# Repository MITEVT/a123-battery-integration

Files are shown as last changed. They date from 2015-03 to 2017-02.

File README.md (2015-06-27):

# a123-battery-integration
Battery Management System for A123 Battery-Brusa Charger combination.
## Target
NXP LPC11Cxx series ARM Cortex-M0
## Description
Interfaces between A123 Module CAN Bus and Brusa CAN Bus and sets appropriate voltage and current profiles. Essentially a battery control module.
### Referenced Library Files
* [EVT's LPC11xx Library](https://github.com/MITEVT/lpc11cx4-library)
* [Unity](https://github.com/ThrowTheSwitch/Unity)

### Requirements
```
gcc-arm-none-eabi
doxygen
oclint
```

### Looking for Examples?
* [EVT's LPC11xx Library](https://github.com/MITEVT/lpc11cx4-library)

### Trying to configure sysinit.c?
Use CMSIS Configuration Wizard v0.0.6
* http://helmpcb.com/software/cmsis-configuration-wizard
* https://sourceforge.net/projects/cmsisconfig/

## More info about our team
http://web.mit.edu/evt/

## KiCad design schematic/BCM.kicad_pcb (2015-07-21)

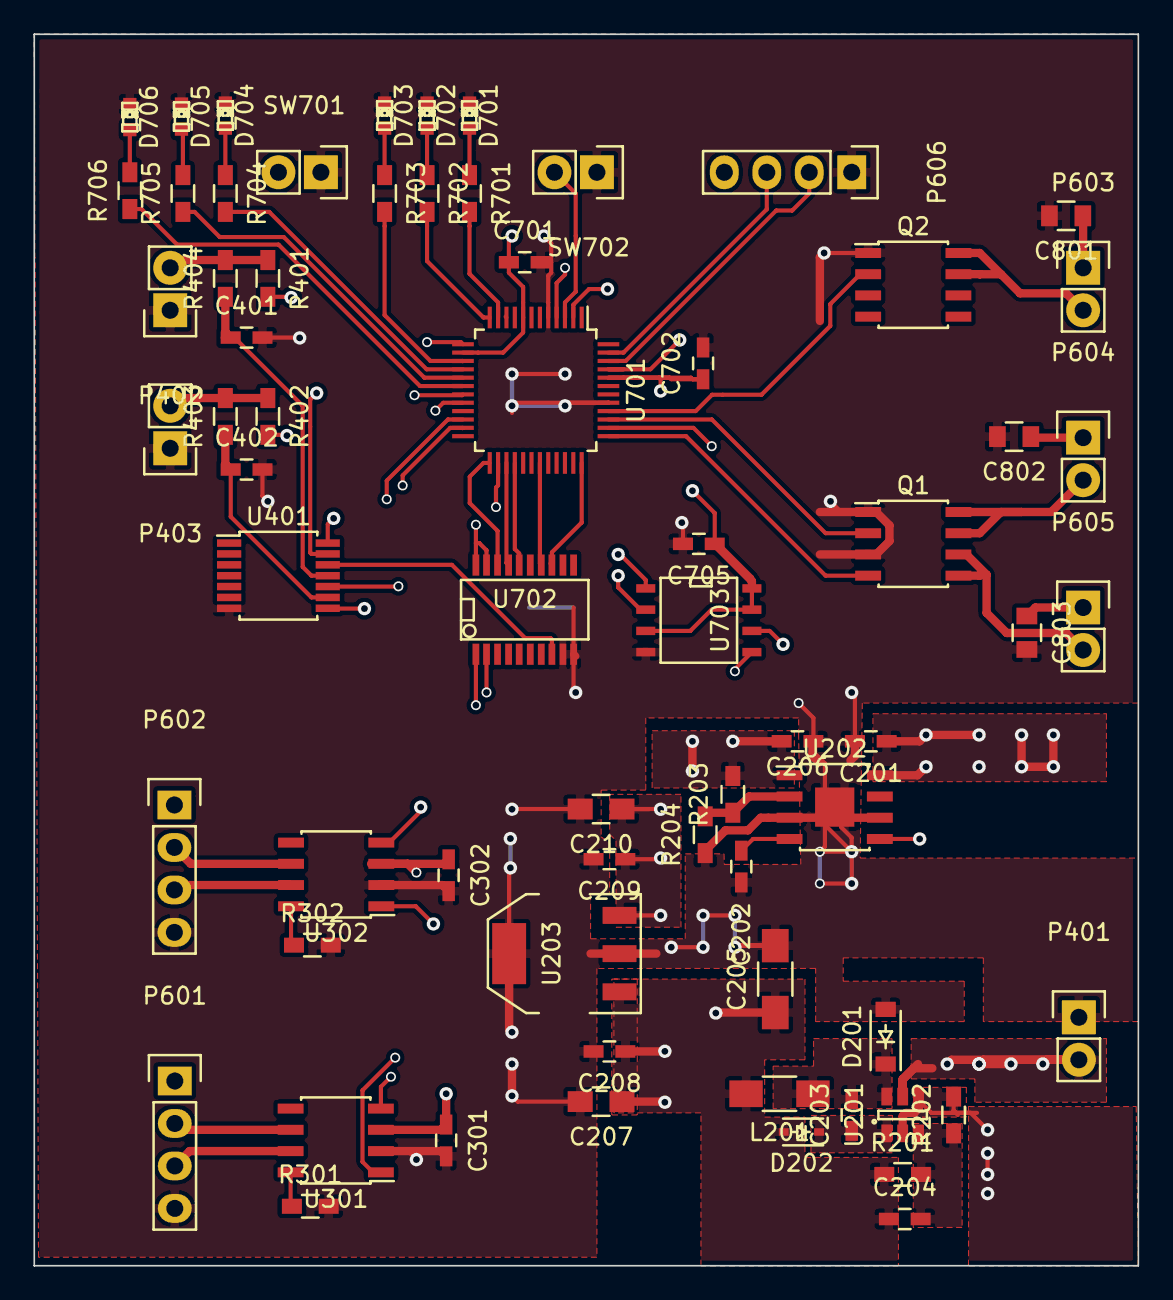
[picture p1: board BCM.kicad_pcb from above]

Board: 4 copper layers, 66.0 x 73.7 mm, 67 parts (0 on the bottom side), 59 nets.

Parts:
C201, C206, C401, C402: 1uF; C_0603_HandSoldering
C202: 10nF; C_0603_HandSoldering
C203: 0.22pF; C_0603_HandSoldering
C204: 10pF; C_0603_HandSoldering
C205: 100uF; C_1206_HandSoldering
C207, C210: 10u; C_0805_HandSoldering
C208, C209, C701, C702: 100n; C_0603_HandSoldering
C301, C302, C705: 0.1uF; C_0603_HandSoldering
C801, C802, C803: 10uF; C_0805
D201: MBR0540; SOD-123
D202: CMDSH-3; SOD-323
D701, D702, D703, D704, D705, D706: RED; LED-0603
L201: 47uH; C_1206_HandSoldering
P401: POWERCON; Pin_Header_Straight_1x02
P402: KEYSWITCH; Pin_Header_Straight_1x02
P403: CHARGESW; Pin_Header_Straight_1x02
P601: BRUSA_CANCON; Pin_Header_Straight_1x04
P602: A123_CANCON; Pin_Header_Straight_1x04
P603: CON+; Pin_Header_Straight_1x02
P604: CON-; Pin_Header_Straight_1x02
P605: CONPRE; Pin_Header_Straight_1x02
P606: UART; Pin_Header_Straight_1x04
Q1, Q2: IRF7101PbF; SOIC-8_3.9x4.9mm_Pitch1.27mm
R201: 1M; R_0603_HandSoldering
R202: 604K; R_0603_HandSoldering
R203: 88.7k; R_0603_HandSoldering
R204: 10k; R_0603_HandSoldering
R301, R302: 33k; R_0603_HandSoldering
R401, R402, R403, R404: 20k; R_0603_HandSoldering
R701, R702, R703, R704, R705, R706: 1k; R_0603_HandSoldering
SW701: ISP; Pin_Header_Straight_1x02
SW702: RESET; Pin_Header_Straight_1x02
U201: LT1934; SOT-23-6
U202: ADP7105; SOIC-8-1EP_3.9x4.9mm_Pitch1.27mm
U203: SPX2920M3-3.3; SOT-223
U301, U302: MCP2551-I/SN; SOIC-8_3.9x4.9mm_Pitch1.27mm
U401: 74LS14; TSSOP-14_4.4x5mm_Pitch0.65mm
U701: LPC11C14; LQFP-48_7x7mm_Pitch0.5mm
U702: MCP2515_TSSOP; SSOP-20
U703: AT25XX; SOIC-8-N

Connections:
+3V3: C209.1, C210.1, C701.1, C702.1, C705.1, R401.2, R402.2, U203.3, U401.14, U701.8, U701.14, U701.44, U702.19, U702.20, U703.3, U703.7, U703.8
+5V: C204.1, C205.1, C207.1, C208.1, C301.1, C302.1, D202.2, L201.2, P606.4, R201.1, U203.1, U301.3, U302.3
+12V: C206.1, P602.1, R203.1, U202.1
+15V: C201.1, C801.1, C802.1, C803.1, P401.2, P603.1, P604.1, P605.1, U201.5, U202.8
/Can transceiver/CAN1_H_I: P601.2, U301.6
/Can transceiver/CAN1_L_I: P601.3, U301.7
/Can transceiver/CAN1_RS: R301.1, U301.8
/Can transceiver/CAN1_RX: U301.4, U702.2
/Can transceiver/CAN1_TX: U301.1, U702.1
/Can transceiver/CAN2_H_I: P602.2, U302.6
/Can transceiver/CAN2_L_I: P602.3, U302.7
/Can transceiver/CAN2_RS: R302.1, U302.8
/Can transceiver/CAN2_RX: U302.4, U701.19
/Can transceiver/CAN2_TX: U302.1, U701.20
/Contactor Driver/CON+: Q2.2, U701.40
/Contactor Driver/CON+_LOW: P603.2, Q2.7, Q2.8
/Contactor Driver/CON-: Q1.2, U701.39
/Contactor Driver/CON-_LOW: P604.2, Q1.7, Q1.8
/Contactor Driver/CONPRE: Q1.4, U701.37
/Contactor Driver/CONPRE_LOW: P605.2, Q1.5, Q1.6
/Input Connectors/CHARGESWITCH_R: P403.2, R402.1, R403.2
/Input Connectors/CHARGESWITCH_RC: C402.1, R403.1, U401.9
/Input Connectors/KEYSKWITCH_RC: C401.1, R404.1, U401.11
/Input Connectors/KEYSWITCH_R: P402.2, R401.1, R404.2
/Power/5V0_BOOST: C203.1, D202.1, U201.1
/Power/5V0_FB: C204.2, R201.2, R202.1, U201.3
/Power/5V0_L: C203.2, D201.1, L201.1, U201.6
/Power/12V0_FB: R203.2, R204.1, U202.2
/Power/12V0_SS: C202.1, U202.4
/Power/EN12V0: U202.5, U701.45
/microController/CAN1_INT: U701.36, U702.13
/microController/CAN1_MISO: U701.27, U702.17
/microController/CAN1_MOSI: U701.28, U702.16
/microController/CAN1_SCK: U701.31, U702.14
/microController/CAN1_SSEL: U701.25, U702.18
/microController/CAN_OSC2: U401.12, U702.8
/microController/CHARGESWITCH_IN: U401.8, U701.22
/microController/CLKOUT: SW701.2, U401.13, U701.4
/microController/IO_LED0: R701.2, U701.11
/microController/IO_LED1: R702.2, U701.12
/microController/IO_LED2: R703.2, U701.15
/microController/IO_LED3: R704.2, U701.16
/microController/IO_LED4: R705.1, U701.17
/microController/IO_LED5: R706.1, U701.18
/microController/KEYSWITCH_IN: U401.10, U701.23
/microController/MCU_RESET: SW702.2, U701.3
/microController/MCU_RXD: P606.2, U701.46
/microController/MCU_TXD: P606.3, U701.47
/microController/PROM_MISO: U701.26, U703.2
/microController/PROM_MOSI: U701.38, U703.5
/microController/PROM_SCK: U701.13, U703.6
/microController/PROM_SSEL: U701.2, U703.1
GND: C201.2, C202.2, C205.2, C206.2, C207.2, C208.2, C209.2, C210.2, C301.2, C302.2, C401.2, C402.2, C701.2, C702.2, C705.2, C801.2, C802.2, C803.2, D201.2, D701.1, D702.1, D703.1, D704.1, D705.1, D706.1, P401.1, P402.1, P403.1, P601.4, P602.4, P606.1, Q1.1, Q1.3, Q2.1, R202.2, R204.2, R301.2, R302.2, SW701.1, SW702.1, U201.2, U201.4, U202.3, U202.6, U202.9, U203.2, U203.4, U301.2, U302.2, U401.7, U701.5, U701.41, U702.9, U702.10, U703.4
unnamed: D701.2, R701.1
unnamed: D702.2, R702.1
unnamed: D703.2, R703.1
unnamed: D704.2, R704.1
unnamed: D705.2, R705.2
unnamed: D706.2, R706.2

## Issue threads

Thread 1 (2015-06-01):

What do you think of this use of GOTO?

ericponce, 2015-06-01:
I used GOTOs to prevent a lag in the updating of output state variables in the charge state machine. I think using this one goto isn't too bad, but let me know what you think

ericponce, 2015-06-01:
Look at charge.c for the referenced code. (Or git diff the last commit)

Closed 2015-11-02.

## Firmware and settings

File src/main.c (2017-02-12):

/**
 * @file main.c
 * @author Eric Ponce
 * @date 23 June 2015
 * @brief Main Program File
 */

#include "board.h"
#include "config.h"
#include <string.h>
#include <stdlib.h>

#define UART_BAUD 57600
#define SPI_BAUD  500000
#define CCAN_BAUD 500000

#define UART_RX_BUF_SIZE 0x8
#define CCAN_BUF_SIZE 0x10

#define MCP_BAUD_KHZ  500
#define MCP_INP_CLK_MHZ 11
#define MCP_SJW 1
#define MCP_CS_GPIO 2
#define MCP_CS_PIN 2
#define MCP_INT_GPIO 0
#define MCP_INT_PIN 2

#define MBB_STD_MSG_OBJ 1
#define MBB_EXT_1_MSG_OBJ 2
#define MBB_EXT_2_MSG_OBJ 3
#define MBB_EXT_3_MSG_OBJ 4
#define MBB_EXT_4_MSG_OBJ 5
#define BCM_STD_MSG_OBJ 6
#define BCM_EXT_MSG_OBJ 7

#define BCM_POLL_IDLE_FREQ 1
#define BCM_POLL_CHARGING_FREQ 40
#define BCM_POLL_DRAINING_FREQ 40
#define BCM_POLL_BALANCING_FREQ 40

#define TIMED_MESSAGE_DELAY 1000

#define BRUSA_MAX_MAINS_CAMPS 1500

#define Hertz2Ticks(freq) SystemCoreClock / freq

#define UpdateBCMTimerFreq(freq) (Chip_TIMER_SetMatch(LPC_TIMER32_1, 0, Hertz2Ticks(freq)))

// ------------------------------------------------
// Global Static Variables

static volatile uint64_t msTicks; // Milliseconds 

// Uart
uint8_t Rx_Buf[UART_RX_BUF_SIZE];
static char str[100]; // For use with printing
// static char int_str[100]; // For use with printing in interrupts

// Off-Chip CAN
static CCAN_MSG_OBJ_T mcp_msg_obj;
static NLG5_CTL_T brusa_control;
static NLG5_STATUS_T brusa_status;
static NLG5_ACT_I_T brusa_actual_1;
static NLG5_ACT_II_T brusa_actual_2;
static NLG5_TEMP_T brusa_temp;
static NLG5_ERR_T brusa_error;
static NLG5_MESSAGES_T brusa_messages;
static volatile bool brusa_message_send = false;

// On-Chip CCAN
static CCAN_MSG_OBJ_T can_msg_obj;
static RINGBUFF_T rx_buffer;
static CCAN_MSG_OBJ_T _rx_buffer[CCAN_BUF_SIZE];
static uint8_t std_msg_send_count;

// A123 CAN Message Structures
static MBB_CMD_T mbb_cmd;

// State staging variables
static volatile bool new_std_msg_sent = true;

// State Variables
static MODE_T mode = IDLE;
static PACK_STATE_T pack_state;
static OUTPUT_STATE_T out_state;

// Timed Print
static uint64_t last_debug_message = 0;
static uint32_t message_count = 0;

// ------------------------------------------------
// Helper functions that don't belong in util because systick, printing, etc

/**
 * @details Relies on SysTick and therefore will not function with interrupts 
 * disabled or in a higher priority interrupt
 * 
 * @param ms number of milliseconds to delay
 */
void _delay_ms(uint32_t ms) {
	uint32_t currTicks = msTicks;
	while(msTicks - currTicks < ms) {

	}
}

/**
 * @details Throws error through multiple means: print, flash, and/or hang
 * 
 * @param errorNo The error number
 * @param flashLED set to true to have processor flash the main LED
 * @param hang set to true to hang the processor
 */
void _error(ERROR_T errorNo, bool flashLED, bool hang) {
	DEBUG_Print("Error(");
	itoa(errorNo, str, 10);
	DEBUG_Print(str);
	DEBUG_Print(")\r\n");

	do { // Hang forevers
		if (flashLED) {
			uint8_t i;
			for (i = 0; i < errorNo; i++) {
				Board_LED_Off();
				_delay_ms(500);
				Board_LED_On();
				_delay_ms(500);
			}
		}
		_delay_ms(1500);
		Board_LED_Off();
	} while(hang);

	Board_LED_On();
}

// ------------------------------------------------
// IRQs

/**
 * @details Increments millisecond counter
 */
void SysTick_Handler(void) {
	msTicks++;
}

/**
 * @details Timer interrupt to maintain Brusa communication timing
 */
void TIMER32_0_IRQHandler(void) {
	if (Chip_TIMER_MatchPending(LPC_TIMER32_0, 0)) {
		Chip_TIMER_ClearMatch(LPC_TIMER32_0, 0);

		brusa_message_send = true;
	}
}

/**
 * @details Timer interrupt to request A123 MBB information
 */
void TIMER32_1_IRQHandler(void) {
	Chip_TIMER_ClearMatch(LPC_TIMER32_1, 0);
	// Update Battery Status
	if (RingBuffer_IsEmpty(&rx_buffer)) {
		// Send BCM_CMD
		mbb_cmd.request_type = BCM_REQUEST_TYPE_STD;
		mbb_cmd.request_id = 5;
		mbb_cmd.balance = out_state.balance;
		mbb_cmd.balance_target_mVolts = out_state.balance_mVolts;

		can_msg_obj.msgobj = BCM_STD_MSG_OBJ;
		MBB_MakeCMD(&mbb_cmd, &can_msg_obj);
		LPC_CCAN_API->can_transmit(&can_msg_obj);	

		new_std_msg_sent = true;
		if (std_msg_send_count++ == 4) {
			std_msg_send_count = 0;

			mbb_cmd.request_type = BCM_REQUEST_TYPE_EXT;
			can_msg_obj.msgobj = BCM_EXT_MSG_OBJ;
			mbb_cmd.request_id = 6;
			MBB_MakeCMD(&mbb_cmd, &can_msg_obj);
			LPC_CCAN_API->can_transmit(&can_msg_obj);

		}
	}
}

// ------------------------------------------------
// CAN Callbacks

/**
 * @details Moves received on-chip CAN messages into ring buffer
 * 
 * @param msg_obj_num CAN message object that received message
 */
void CAN_rx(uint8_t msg_obj_num) {
	/* Determine which CAN message has been received */
	can_msg_obj.msgobj = msg_obj_num;
	/* Now load up the msg_obj structure with the CAN message */
	LPC_CCAN_API->can_receive(&can_msg_obj);
	RingBuffer_Insert(&rx_buffer, &can_msg_obj);
}


/**
 * @details On-chip CAN transmit callback. Currently does nothing
 * 
 * @param msg_obj_num CAN message object that sent message
 */
void CAN_tx(uint8_t msg_obj_num) {
	msg_obj_num++;
}

/**
 * @details On-chip CAN error callback. Currently does nothing
 * 
 * @param error_info error info
 */
void CAN_error(uint32_t error_info) {
	error_info++;
	DEBUG_Print("On-chip CAN Error\n\r");
	// _error(error_info, true, false);
}

// ------------------------------------------------
// Init Functions

/**
 * @details Initializes SysTick Peripheral
 */
void Init_Core(void) {
	SystemCoreClockUpdate();

	msTicks = 0; 

	// ------------------------------------------------
	// Systick Config
	if (SysTick_Config (SystemCoreClock / 1000)) {
		//Error
		while(1);
	}
}

/**
 * @details Initializes state machines and sets configuration data
 */
void Init_SM(void) {

	CHARGING_CONFIG_T charge_config;
	charge_config.pack_s = CELL_SERIES;
	charge_config.pack_p = CELL_PARALLEL;
	charge_config.max_cell_mVolts = 3600;
	charge_config.cc_cell_mVolts = 3700;
	charge_config.cell_capacity_cAmpHours = 2000; 	// 20 Ahr
	charge_config.cell_mC_rating = 133; 			// .133 C

	DRAINING_CONFIG_T drain_config;
	drain_config.min_cell_mVolts = 2500; //Specs say 2000mV but lets play it safe for now

	Charge_Config(&charge_config);
	Drain_Config(&drain_config);
	SSM_Init();
	PackManager_Init();

}

/**
 * @details Initializes board peripherals
 */
void Init_Board(void) {
	// ------------------------------------------------
	// Board Periph Init
	Board_LED_Init();
	Board_LED_On();
	Board_Switch_Init(SWITCH1);
	Board_Switch_Init(SWITCH2);
	Board_Contactors_Init();

	// ------------------------------------------------
	// Communication Init

	Board_UART_Init(UART_BAUD);
	Board_SPI_Init(SPI_BAUD);
	Board_CCAN_Init(CCAN_BAUD, CAN_rx, CAN_tx, CAN_error);
}

/**
 * @details Initializes statically allocated global variables
 */
void Init_Globals(void) {
	brusa_control.enable = 1;
	brusa_control.clear_error = 0;
	brusa_control.ventilation_request = 1;
	brusa_control.max_mains_cAmps = BRUSA_MAX_MAINS_CAMPS;
	brusa_control.output_mV = 0;
	brusa_control.output_cA = 0;

	pack_state.pack_min_mVolts = 0xFFFFFFFF;
	pack_state.pack_max_mVolts = 0;
	pack_state.pack_cAmps_in = 0;

	out_state.balance_mVolts = BCM_BALANCE_OFF;
	out_state.balance = false;
	out_state.brusa_mVolts = 0;
	out_state.brusa_cAmps = 0;
	out_state.close_contactors = false;
	out_state.brusa_output = false;
	out_state.brusa_clear_latch = false;

	mode = IDLE;

	std_msg_send_count = 0;

	brusa_messages.stat = &brusa_status;
	brusa_messages.act_i = &brusa_actual_1;
	brusa_messages.act_ii = &brusa_actual_2;
	brusa_messages.temp = &brusa_temp;
	brusa_messages.err = &brusa_error;
}

/**
 * @details Initializes both on-chip and off-chip CAN and sets up filters and masks.
 */
void Init_CAN(void) {
	// ------------------------------------------------
	// MCP2515 Init
	MCP2515_Init(MCP_CS_GPIO, MCP_CS_PIN, MCP_INT_GPIO, MCP_INT_PIN);
	uint8_t i = MCP2515_SetBitRate(MCP_BAUD_KHZ, MCP_INP_CLK_MHZ, MCP_SJW);
	itoa(i, str, 10);
	if (i) {
		DEBUG_Print("Baud Error: ");
		DEBUG_Print(str);
		DEBUG_Print("\r\n");
		_error(ERROR_CAN_BUS, true, true);
	}

	Brusa_MakeCTL(&brusa_control, &mcp_msg_obj);
	MCP2515_LoadBuffer(0, &mcp_msg_obj);

	MCP2515_BitModify(RXB0CTRL, RXM_MASK, RXM_STD); //Turn RXB0 Mask
	MCP2515_BitModify(RXB1CTRL, RXM_MASK, RXM_STD);
	MCP2515_BitModify(RXF0SIDH, 0xFF, 0xC2);
	MCP2515_BitModify(RXF0SIDL, 0xE0, 0x00); // Message 610
	MCP2515_BitModify(RXF1SIDH, 0xFF, 0xC2);
	MCP2515_BitModify(RXF1SIDL, 0xE0, 0x80); // Message 614
	MCP2515_BitModify(RXM0SIDH, 0xFF, 0xFF);
	MCP2515_BitModify(RXM0SIDL, 0xE0, 0xE0); // Buffer 0 gets odd
	MCP2515_BitModify(RXF2SIDH, 0xFF, 0xC2);
	MCP2515_BitModify(RXF2SIDL, 0xE0, 0x20); // Message 611
	MCP2515_BitModify(RXF3SIDH, 0xFF, 0xC2);
	MCP2515_BitModify(RXF3SIDL, 0xE0, 0x60); // Message 613
	MCP2515_BitModify(RXF4SIDH, 0xFF, 0xC2);
	MCP2515_BitModify(RXF4SIDL, 0xE0, 0x20); // Message 611
	MCP2515_BitModify(RXF5SIDH, 0xFF, 0xC2);
	MCP2515_BitModify(RXF5SIDL, 0xE0, 0x20); // Message 611
	MCP2515_BitModify(RXM1SIDH, 0xFF, 0xFF);
	MCP2515_BitModify(RXM1SIDL, 0xE0, 0xE0); // Buffer 1 gets even

	MCP2515_Mode(MODE_NORMAL);

	// ------------------------------------------------
	// On-Chip CCAN Init
	RingBuffer_Init(&rx_buffer, _rx_buffer, sizeof(CCAN_MSG_OBJ_T), 8);
	RingBuffer_Flush(&rx_buffer);

	// MBB_STD
	can_msg_obj.msgobj = MBB_STD_MSG_OBJ;
	can_msg_obj.mode_id = 0x200;
	can_msg_obj.mask = 0xF00;
	LPC_CCAN_API->config_rxmsgobj(&can_msg_obj);

	// MBB_EXT_1
	can_msg_obj.msgobj = MBB_EXT_1_MSG_OBJ;
	can_msg_obj.mode_id = 0x300;
	can_msg_obj.mask = 0xF00;
	LPC_CCAN_API->config_rxmsgobj(&can_msg_obj);

	// MBB_EXT_2
	can_msg_obj.msgobj = MBB_EXT_2_MSG_OBJ;
	can_msg_obj.mode_id = 0x400;
	can_msg_obj.mask = 0xF00;
	LPC_CCAN_API->config_rxmsgobj(&can_msg_obj);

	// MBB_EXT_3
	can_msg_obj.msgobj = MBB_EXT_3_MSG_OBJ;
	can_msg_obj.mode_id = 0x500;
	can_msg_obj.mask = 0xF00;
	LPC_CCAN_API->config_rxmsgobj(&can_msg_obj);

	// MBB_EXT_4
	can_msg_obj.msgobj = MBB_EXT_4_MSG_OBJ;
	can_msg_obj.mode_id = 0x600;
	can_msg_obj.mask = 0xF00;
	LPC_CCAN_API->config_rxmsgobj(&can_msg_obj);
}

/**
 * @details Initiizes timers for timer based interrupts
 */
void Init_Timers(void) {
	// ------------------------------------------------
	// Timer 32_0 Init
	Chip_TIMER_Init(LPC_TIMER32_0);
	Chip_TIMER_Reset(LPC_TIMER32_0);
	Chip_TIMER_MatchEnableInt(LPC_TIMER32_0, 0);
	Chip_TIMER_SetMatch(LPC_TIMER32_0, 0, Hertz2Ticks(10));
	Chip_TIMER_ResetOnMatchEnable(LPC_TIMER32_0, 0);

    // Chip_TIMER_Enable(LPC_TIMER32_0);

	/* Enable timer interrupt */
	NVIC_ClearPendingIRQ(TIMER_32_0_IRQn);
	NVIC_EnableIRQ(TIMER_32_0_IRQn);

	// ------------------------------------------------
	// Timer 32_0 Init
	Chip_TIMER_Init(LPC_TIMER32_1);
	Chip_TIMER_Reset(LPC_TIMER32_1);
	Chip_TIMER_MatchEnableInt(LPC_TIMER32_1, 0);
	Chip_TIMER_SetMatch(LPC_TIMER32_1, 0, Hertz2Ticks(BCM_POLL_IDLE_FREQ));
	Chip_TIMER_ResetOnMatchEnable(LPC_TIMER32_1, 0);

	/* Enable timer_32_1 interrupt */
	NVIC_ClearPendingIRQ(TIMER_32_1_IRQn);
	NVIC_EnableIRQ(TIMER_32_1_IRQn);

	Chip_TIMER_Enable(LPC_TIMER32_1);
}


// ------------------------------------------------
// Main Program

/**
 * @details Where all the magic happens
 * @return Shouldn't return
 */
int main(void) {

	Init_Core();
	Init_SM();
	Init_Board();
	Init_Globals();
	Init_CAN();
	Init_Timers();

	// ------------------------------------------------
	// Begin

	DEBUG_Print("Started Up\r\n");

	while(1) {

		uint8_t count;
		if ((count = Chip_UART_Read(LPC_USART, Rx_Buf, UART_RX_BUF_SIZE)) != 0) {
			switch (Rx_Buf[0]) {
				case 'a': // Print out Brusa Mains Info
					DEBUG_Print("Actual Mains Voltage: ");
					itoa(brusa_actual_1.mains_mVolts, str, 10);
					DEBUG_Print(str);
					DEBUG_Print("\r\n");

					DEBUG_Print("Mains type: ");
					itoa(brusa_actual_1.mains_cAmps, str, 10);
					DEBUG_Print(str);
					DEBUG_Print("\r\n");

					DEBUG_Print("Temp: ");
					itoa((brusa_temp.power_temp / 10) - 40 , str, 10);
					DEBUG_Print(str);
					DEBUG_Print("\r\n");

					DEBUG_Print("Temp: 0x");
					itoa(brusa_temp.power_temp , str, 16);
					DEBUG_Print(str);
					DEBUG_Print("\r\n");
					break;
				case 'b': // Print out Actual Brusa Output
					DEBUG_Print("Actual Out Voltage: ");
					itoa(brusa_actual_1.output_mVolts, str, 10);
					DEBUG_Println(str);

					DEBUG_Print("Actual Out Current: ");
					itoa(brusa_actual_1.output_cAmps, str, 10);
					DEBUG_Println(str);
					break;
				case 'f': // Print out Pack State
					itoa(pack_state.pack_min_mVolts, str, 10);
					DEBUG_Print("Pack Min Voltage: ");
					DEBUG_Print(str);
					DEBUG_Print("\r\n");
					itoa(pack_state.pack_max_mVolts, str, 10);
					DEBUG_Print("Pack Max Voltage: ");
					DEBUG_Print(str);
					DEBUG_Print("\r\n");

					break;
				case 'y': // Print out Module Balance State
					itoa(PackManager_GetExtModId(0), str, 16);
					DEBUG_Print("Mod 0x");
					DEBUG_Print(str);
					itoa(PackManager_GetExtBal(0), str, 2);
					DEBUG_Print(": 0b");
					DEBUG_Println(str);
					itoa(PackManager_GetExtModId(1), str, 16);
					DEBUG_Print("Mod 0x");
					DEBUG_Print(str);
					itoa(PackManager_GetExtBal(1), str, 2);
					DEBUG_Print(": 0b");
					DEBUG_Println(str);
					break;
				case 'e': 
					itoa(brusa_error,str, 2);
					DEBUG_Println(str);
					break;
				case 'm': // Print out charge mode and brusa error
					DEBUG_Print("Charge Mode: ");
					itoa(Charge_GetMode(), str, 10);
					DEBUG_Println(str);
					DEBUG_Print("Error Messages: ");
					itoa((uint64_t)brusa_error, str, 2);
					DEBUG_Println(str);
					break;
				default:
					DEBUG_Print("Unknown Command\r\n");
			}
		}

		//-----------------------------
		// Detect Input Changes (Default to IDLE)

		MODE_INPUT_T inp = INP_IDLE;
		if (!Board_Switch_Read(SWITCH1)) {
			inp = INP_CHRG;
		} else {
			inp = INP_IDLE;
		}

		if (!Board_Switch_Read(SWITCH2)) {
			inp = INP_BALANCE;
		}

		//-----------------------------
		// Update pack_state
		pack_state.contactors_closed = Board_Contactors_Closed();
		pack_state.msTicks = msTicks;
		pack_state.brusa_error = brusa_error;
		pack_state.pack_cAmps_in = brusa_actual_1.output_cAmps;

		//-----------------------------
		// SSM Step
		ERROR_T result = SSM_Step(&pack_state, inp, &out_state);
		if (result != ERROR_NONE) {
			_error(result, true, false);
		}

		//-----------------------------
		// Check if SSM has Changed State
		// Currently only changes Poll Frequency
		// [TODO] Set a status LED!!
		if (SSM_GetMode() != mode) {
			mode = SSM_GetMode();
			switch (SSM_GetMode()) {
				case IDLE:
					Chip_TIMER_SetMatch(LPC_TIMER32_1, 0, Hertz2Ticks(BCM_POLL_IDLE_FREQ));
					Chip_TIMER_Reset(LPC_TIMER32_1); // Otherwise shit gets FUCKED
					break;
				case CHARGING:
					Chip_TIMER_SetMatch(LPC_TIMER32_1, 0, Hertz2Ticks(BCM_POLL_CHARGING_FREQ));
					Chip_TIMER_Reset(LPC_TIMER32_1);
					break;
				case DRAINING:
					Chip_TIMER_SetMatch(LPC_TIMER32_1, 0, Hertz2Ticks(BCM_POLL_DRAINING_FREQ));
					Chip_TIMER_Reset(LPC_TIMER32_1);
					break;
				case BALANCING:
					Chip_TIMER_SetMatch(LPC_TIMER32_1, 0, Hertz2Ticks(BCM_POLL_BALANCING_FREQ));
					Chip_TIMER_Reset(LPC_TIMER32_1);
					break;
			}
		}

		//-----------------------------
		// Carry out out_state
		if (out_state.close_contactors && !Board_Contactors_Closed()) {
			Board_Close_Contactors(true);
		} else if (!out_state.close_contactors && Board_Contactors_Closed()) {
			Board_Close_Contactors(false);
		}

		if (out_state.brusa_output) {
			brusa_control.clear_error = out_state.brusa_clear_latch;
			brusa_control.output_mV = out_state.brusa_mVolts;
			brusa_control.output_cA = out_state.brusa_cAmps;
			Chip_TIMER_Enable(LPC_TIMER32_0);
		} else {
			brusa_control.output_mV = 0;
			brusa_control.output_cA = 0;
			Chip_TIMER_Disable(LPC_TIMER32_0);
		}

		//-----------------------------
		// Retrieve available brusa messages
		int8_t tmp = MCP2515_GetFullReceiveBuffer();
		int8_t res = 0;
		if (tmp == 2) {
			MCP2515_ReadBuffer(&mcp_msg_obj, 0);
			res = Brusa_Decode(&brusa_messages, &mcp_msg_obj);
			if (res == -1) {
				DEBUG_Println("Brusa Decode Error");
				res = 0;
			}
			MCP2515_ReadBuffer(&mcp_msg_obj, 1);
			res = Brusa_Decode(&brusa_messages, &mcp_msg_obj);
		} else if (tmp == 0) { // Receive Buffer 0 Full
			MCP2515_ReadBuffer(&mcp_msg_obj, tmp);
			res = Brusa_Decode(&brusa_messages, &mcp_msg_obj);
		} else if (tmp == 1) { //Receive buffer 1 full
			MCP2515_ReadBuffer(&mcp_msg_obj, tmp);
			res = Brusa_Decode(&brusa_messages, &mcp_msg_obj);
		} 

		if (res == -1) {
			DEBUG_Println("Brusa Decode Error");
			res = 0;
		}

		//-----------------------------
		// Send brusa message if its time
		if (brusa_message_send) {
			brusa_message_send = false;
			Brusa_MakeCTL(&brusa_control, &mcp_msg_obj);
			MCP2515_LoadBuffer(0, &mcp_msg_obj);
			MCP2515_SendBuffer(0);
		}
		
		//-----------------------------
		// Check for and decode A123 Messages
		if (!RingBuffer_IsEmpty(&rx_buffer)) {

			CCAN_MSG_OBJ_T temp_msg;
			RingBuffer_Pop(&rx_buffer, &temp_msg);
			res = PackManager_Update(&temp_msg);

			if (new_std_msg_sent) {
				PackManager_Commit(&pack_state);
				new_std_msg_sent = false;
			}
			
		}

		if (res == -1) {
			DEBUG_Println("A123 Decode Error");
		}

		//-----------------------------
		// Timed output
		if (msTicks - last_debug_message > TIMED_MESSAGE_DELAY) {
			message_count++;
			last_debug_message = msTicks;
			switch (message_count % 7) {
				case 0:
					if (out_state.balance) {
						itoa(mbb_cmd.balance_target_mVolts, str, 10);
						DEBUG_Print("Balancing to: ");
						DEBUG_Println(str);
					} else {
						DEBUG_Println("Not balancing");
					}
					
					break;
				case 1:
					itoa(brusa_control.output_mV, str, 10);
					DEBUG_Print("Brusa out V: ");
					DEBUG_Println(str);
					break;
				case 2:
					itoa(brusa_control.output_cA, str, 10);
					DEBUG_Print("Brusa out C: ");
					DEBUG_Println(str);
					break;
				case 3:
					DEBUG_Print("Actual Out Voltage: ");
					itoa(brusa_actual_1.output_mVolts, str, 10);
					DEBUG_Println(str);
					break;
				case 4:
					DEBUG_Print("Actual Out Current: ");
					itoa(brusa_actual_1.output_cAmps, str, 10);
					DEBUG_Println(str);
					break;
				case 5:
					DEBUG_Print("Mode: ");
					if (SSM_GetMode() == CHARGING) {
						DEBUG_Println("Chrg");
					} else if (SSM_GetMode() == DRAINING) {
						DEBUG_Println("Drain");
					} else if (SSM_GetMode() == BALANCING) {
						DEBUG_Println("Bal");
					} else if (SSM_GetMode() == IDLE) {
						DEBUG_Println("Idle");
					} else {
						DEBUG_Println("Unknown");
					}
					break;
				case 6:
					DEBUG_Print("Brusa Output: ");
					itoa(out_state.brusa_output, str, 2);
					DEBUG_Println(str);

					DEBUG_Print("\r\n");
					break;

			}
		}
	}

	return 0;
}

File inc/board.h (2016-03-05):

/**
 * @file board.h
 * @author Eric Ponce
 * @date 25 June 2015
 * @brief Board peripheral driver
 */

#ifndef _BOARD_H_
#define _BOARD_H_

#include "chip.h"
#include "state_types.h"
#include "mcp2515.h"
#include "brusa.h"
#include "a123mbb.h"
#include "util.h"
#include "charge.h"
#include "drain.h"
#include "ssm.h"
#include "pack_manager.h"

#define LED1_GPIO 2
#define LED1_PIN 10

#define LED2_GPIO 3
#define LED2_PIN 0

#define LED3_GPIO 3
#define LED3_PIN 1

#define LED4_GPIO 3
#define LED4_PIN 2

#define LED5_GPIO 3
#define LED5_PIN 3

#define SWITCH1_GPIO 0
#define SWITCH1_PIN  1
#define SWITCH1 SWITCH1_GPIO, SWITCH1_PIN

#define SWITCH2_GPIO 1
#define SWITCH2_PIN 8
#define SWITCH2 SWITCH2_GPIO, SWITCH2_PIN

#define CONTACTOR_P_GPIO 	2
#define CONTACTOR_P_PIN  	8
#define CONTACTOR_N_GPIO 	2
#define CONTACTOR_N_PIN  	7
#define CONTACTOR_PRE_GPIO 	2
#define CONTACTOR_PRE_PIN 	1

#define DEBUG_ENABLE

#ifdef DEBUG_ENABLE
	#define DEBUG_Print(str) Chip_UART_SendBlocking(LPC_USART, str, strlen(str))
	#define DEBUG_Println(str) {DEBUG_Print(str); DEBUG_Print("\r\n");}
	#define DEBUG_Write(str, count) Chip_UART_SendBlocking(LPC_USART, str, count)
#else
	#define DEBUG_Print(str)
	#define DEBUG_Println(str)
	#define DEBUG_Write(str, count) 
#endif


/**
 * @details Initialize the UART used for debugging
 * 
 * @param baudRateHz the desired baud rate
 */
void Board_UART_Init(uint32_t baudRateHz);

/**
 * @details Initialize the SPI0 peripheral used in off-chip CAN
 * 
 * @param baudRateHz the desired baud rate
 */
void Board_SPI_Init(uint32_t baudRateHz);

/**
 * @details Initialize the on-chip CAN peripheral
 * 
 * @param baudRateHz the desired baud rate
 * @param CAN_rx CAN RX callback function
 * @param CAN_tx CAN TX callback function
 * @param CAN_error CAN error callback function
 */
void Board_CCAN_Init(uint32_t baudRateHz, void (*CAN_rx)(uint8_t), void (*CAN_tx)(uint8_t), void (*CAN_error)(uint32_t));

/**
 * @details Initialize Board Status LED
 */
void Board_LED_Init(void);

/**
 * @details Turn status LED on
 */
void Board_LED_On(void);

/**
 * @details Turn status LED off
 */
void Board_LED_Off(void);

/**
 * @details Initialize board input switch
 */
void Board_Switch_Init(uint8_t port, uint8_t pin);

/**
 * @details Get board input switch state
 * @return state of switch
 */
bool Board_Switch_Read(uint8_t port, uint8_t pin);

/**
 * @details Initialize contactors
 */
void Board_Contactors_Init(void);

/**
 * @details Close or open the contactors
 * @param close Whether or no to close the contactors
 */
void Board_Close_Contactors(bool close);

/**
 * @details Get state of contactors
 * @return state of contactors
 */
bool Board_Contactors_Closed(void);

extern void CAN_rx(uint8_t msg_obj_num);
extern void CAN_tx(uint8_t msg_obj_num);
extern void CAN_error(uint32_t error_info);

#endif

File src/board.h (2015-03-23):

#include "chip.h"
#include <string.h>

#define LED1_GPIO 2
#define LED1_PIN 10

#define SWITCH_GPIO 0
#define SWITCH_PIN  1

#define CONTACTOR_P_GPIO 	2
#define CONTACTOR_P_PIN  	6
#define CONTACTOR_N_GPIO 	2
#define CONTACTOR_N_PIN  	7
#define CONTACTOR_PRE_GPIO 	2
#define CONTACTOR_PRE_PIN 	10

#define DEBUG_ENABLE

#ifdef DEBUG_ENABLE
	#define DEBUG_Print(str) Chip_UART_SendBlocking(LPC_USART, str, strlen(str))
	#define DEBUG_Write(str, count) Chip_UART_SendBlocking(LPC_USART, str, count)
#else
	#define DEBUG_Print(str)
	#define DEBUG_Write(str, count) 
#endif


void Board_UART_Init(uint32_t baudRateHz);

void Board_SPI_Init(uint32_t baudRateHz);

void Board_CCAN_Init(uint32_t baudRateHz, void (*CAN_rx)(uint8_t), void (*CAN_tx)(uint8_t), void (*CAN_error)(uint32_t));

void Board_LED_Init(void);
void Board_LED_On(void);
void Board_LED_Off(void);

void Board_Switch_Init(void);
bool Board_Switch_Read(void);

void Board_Contactors_Init(void);
bool Board_Contactors_On(void);
bool Board_Contactors_Off(void);

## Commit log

2015-01-18 [build] changed device include to be included
2015-02-03 Seperated debug printing
2015-03-23 Added some contactor code to charging segment
2015-03-23 Moved Battery Monitoring code to Timer Interrupt
    Realized that this has to always happen, whether charging, discharging, or just idling. So why not simply increase and decrease the frequency based on mode and put it in a timer interrupt. But then t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
2015-03-23 Added a silly syntax fix
    [main.c]
2015-04-04 added first schematic
    [a123-battery-integration.sch]
2015-04-04 Updated Charging Mode
2015-04-04 Created initial schematic with MCU and CAN tranceivers
    [a123-battery-integration.sch]
2015-04-04 Fix: added regulator capacitors
2015-04-11 [SCHEMATIC] swapped MCP2551 for ISO1050, small changes, updated package associations
    [a123-battery-integration.kicad_pcb, a123-battery-integration.sch]
2015-04-25 started schematic as a higherarchy
    [BCM.sch, CAN_Isolator.sch, HV_sense.sch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]
2015-05-02 continued work on splitting the schematic
    [BCM.sch, HV_sense.sch, inutConnectors.sch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]
2015-05-02 Rewrote Charge statemachine and fixed tests
    [board.h, main.c]
2015-05-02 [schematic] editing power added extra schematics
    [BCM.sch, CAN_Isolator.sch, HV_sense.sch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]
2015-05-02 added more schematic things
    [BCM.sch, HV_sense.sch]
2015-05-02 [schematic] finished HV sense
    [HV_sense.sch]
2015-05-02 changes to microController schematic
    [BCM.sch, CAN_Isolator.sch, HV_sense.sch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]
2015-05-02 fixed connections
    [BCM.sch, CAN_Isolator.sch, HV_sense.sch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]
2015-05-02 fixed connections, updated kicad version
    [BCM.sch, CAN_Isolator.sch, HV_sense.sch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]
2015-05-02 isolation changes
    [BCM.sch, CAN_Isolator.sch, HV_sense.sch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]
2015-05-02 [schematic] more decoupling
    [HV_sense.sch, microController.sch, power.sch]
2015-05-02 [schematic] changed micro added isolated tranceiver and cleaned
    [BCM.sch, CAN_Isolator.sch, HV_sense.sch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]
2015-05-09 Ported over Charge and Drain state machines to new unit system
2015-05-09 Added new test cases and fixed new unit system
    [main.c]
2015-05-09 Fixed CAN_error bug (interrupt using msTicks hangs)
    [main.c]
2015-05-09 added switch debouncing
    [BCM.sch, inutConnectors.sch]
2015-06-01 Used GOTO to remove charge statemachine value lag
2015-06-06 [schematic] changed stuff
    [BCM.sch, CAN_Isolator.sch, HV_sense.sch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]
2015-06-06 added contactor drive moduels and interupt pin on MCP2515
    [BCM.sch, CAN_Isolator.sch, HV_sense.sch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]
2015-06-06 [schematic] added contactor drive circuits and improved system wiring
    [BCM.sch, contactorDriver.sch, power.sch]
2015-06-10 Fixed bugs including, SSP Timing errors, Incorrect Addressing
    [main.c]
2015-06-11 Updated Drain SM to follow charge sm template
2015-06-11 Moved charge sm over to new return types
2015-06-12 [schematic] I honestly don't remember
    [BCM.sch, CAN_Isolator.sch, HV_sense.sch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]
2015-06-12 [schematic] basically finished with the schematic
    [BCM.sch, CAN_Isolator.sch, contactorDriver.sch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]
2015-06-13 [schematic] selected I2C resistors
    [microController.sch]
2015-06-13 [schematic] renamed can tranceiver sub schematic
    [BCM.sch, CAN_transceiver.sch]
2015-06-13 [schematic] added lables to all input connector nodes
    [inutConnectors.sch]
2015-06-13 [schematic] added labels on power sheet
    [power.sch]
2015-06-13 [schematic] added labels to CAN transceiver
    [CAN_transceiver.sch]
2015-06-13 [schematic] modified micro controller labels
    [microController.sch]
2015-06-13 [schematic] annotated all components
    [BCM.sch, CAN_transceiver.sch, contactorDriver.sch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]
2015-06-13 fixed component library issue
    [BCM.sch, CAN_transceiver.sch, contactorDriver.sch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]
2015-06-13 [schematic] re-added switch and net lable that were mistakenly deleted
    [microController.sch]
2015-06-13 [schematic] removed last reference to +3.3VP
    [microController.sch]
2015-06-14 Moved over to milli c rating and moved a123 decode out of interrupt
2015-06-18 Incororated oclint into makefile and fixed some shit
    [board.c, main.c]
2015-06-19 [schematic][netlist][footprint] added UART to output connectors. first pass at footprints. footprints incomplete
    [BCM.sch, CAN_transceiver.sch, contactorDriver.sch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]
2015-06-20 Updated code to properly initialize Brusa and clear latch errors
    [main.c]
2015-06-20 Cleaned up code and potentially fixed delayed charge start bug
    [main.c]
2015-06-20 [packages] component association
    [CAN_transceiver.sch, inutConnectors.sch, microController.sch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]
2015-06-20 replaced contactor driver MOSFETs with IRF7101PbF parts
    [contactorDriver.sch]
2015-06-20 added footprint associations for 60Mhz crystal and others
    [contactorDriver.sch, inutConnectors.sch, microController.sch]
2015-06-20 initial layout commit
    [BCM.kicad_pcb, contactorDriver.sch, microController.sch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]
2015-06-20 Added staged updating and fixed turn off bug. Tested and charging fucign works
    [main.c]
2015-06-20 layout: most parts done, fill zones in progress
    [BCM.kicad_pcb]
2015-06-27 [layout] went to 4 layers nearly done
    [BCM.kicad_pcb, contactorDriver.sch, inutConnectors.sch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]
2015-06-27 Created a pack manager for staged updates and moved configuration information to config.h
2015-07-01 Cleaned up code, modified charge sm, and added tests
2015-07-01 [routing] finished routing passed all DRCs moved pins to accomodate routing
    [BCM.kicad_pcb, microController.sch]
2015-07-21 Final change before fab
    [BCM.kicad_pcb]
2017-02-12 Fixed compilation errors stemming from updated lpc_libs
    [main.c]
